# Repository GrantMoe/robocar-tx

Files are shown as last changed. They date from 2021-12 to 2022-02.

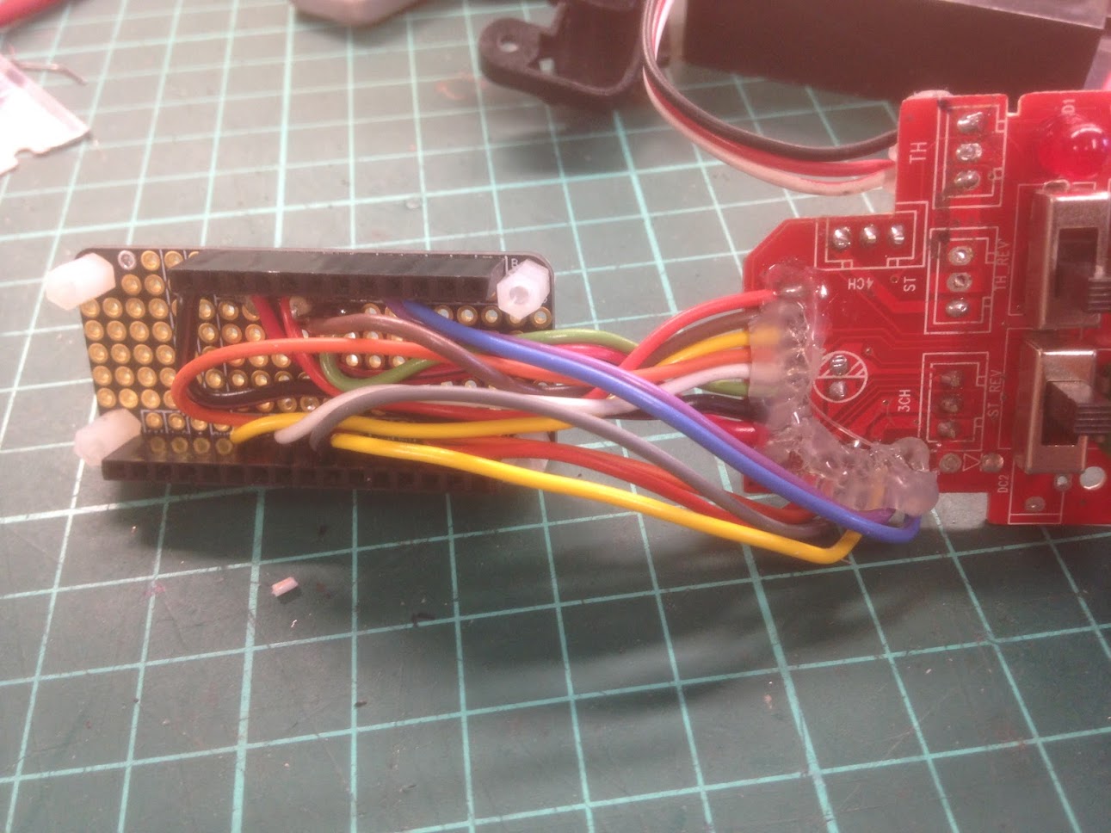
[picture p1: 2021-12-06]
mess_of_wires.JPG

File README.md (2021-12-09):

# BLE Robocar Controller

I'm building an autonomous RC car to participate in diy [DIYRobocar](https://diyrobocars.com/) events.

My 2-channel RC radio wasn't cutting it, so I decided to make my own BLE controller.

### Components

* [Adafruit Feather nRF52 Bluefruit LE - nRF52832](https://www.adafruit.com/product/3406)
* [Adafruit Mini Color TFT with Joystick FeatherWing](https://www.adafruit.com/product/3321)

### Todo
- [x] analog input for steering, throttle, trim pots, switches, etc
- [x] TFT/seesaw joystick and button input 
- [x] approximate Arduino's Serial dislpay via TFT screen
- [x] transmit control inputs to car
- [x] implement other car parameters (end stops, center point, max throttle, etc.) in software
- [ ] TFT menu to manipulate the above parameters
- [ ] send paramater changes to the car
- [ ] get state from car 

### tbd
* proper refresh rate

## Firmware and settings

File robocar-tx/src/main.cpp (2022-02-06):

#include <Arduino.h>
#include <Adafruit_GFX.h>
#include <Adafruit_ST7735.h>
#include <bluefruit.h>

#include "Adafruit_miniTFTWing.h"
#include "Axis.h"
#include "tx.h"

BLEDis  bledis;
BLEHidGamepad blegamepad;

// defined in hid.h from Adafruit_TinyUSB_Arduino
hid_gamepad_report_t gp;

Adafruit_miniTFTWing ss;
Adafruit_ST7735 tft = Adafruit_ST7735(TFT_CS_PIN, TFT_DC_PIN, TFT_RST_PIN);
// GFXcanvas1 canvas(tft.width(), tft.height());
// Tx_tft tx_display(tft, canvas);

// in, trim, exp, rev
Axis steering(ST_PIN, ST_TRM_PIN, ST_EXP_PIN, ST_REV_PIN);
Axis throttle(TH_PIN, TH_TRM_PIN, TH_EXP_PIN, TH_REV_PIN);

String id_str = "EF:EB:FD:C7:F8:DA";
int current_mode;
int previous_mode;
bool reversed = true;

// TODO: callbacks can be useful for hand unit display, actually.
void connect_callback(uint16_t);
void disconnect_callback(uint16_t, uint8_t);
void startAdv(void);
int read_slider(int);
void show_menu(int);
void print_scroll(String);
int miniTFTWing_gamepad_buttons(int, bool);
int miniTFTWing_gamepad_hat(int, bool);


const unsigned long tft_buttons[] = {
  TFTWING_BUTTON_DOWN,
  TFTWING_BUTTON_UP,
  TFTWING_BUTTON_RIGHT,
  TFTWING_BUTTON_LEFT,
  TFTWING_BUTTON_SELECT,
  TFTWING_BUTTON_A,
  TFTWING_BUTTON_B
};

const String menu_strings_[3][3] = {
  {"", "", "Drive"},
  {"confirm", "cancel", "Cal."},
  {"center", "calibrate", "Pause"}
};

bool pressed[NUM_BUTTONS];
unsigned long last_pressed[NUM_BUTTONS];


void setup() {

  for (int i =0; i < NUM_BUTTONS; i++) {
    pressed[i] = false;
    last_pressed[i] = millis();
  }
  // set reverse switch pullups
  // do in axis instead?
  pinMode(ST_REV_PIN, INPUT_PULLUP);
  pinMode(TH_REV_PIN, INPUT_PULLUP);
  pinMode(CH_4_PIN, INPUT);

  Serial.begin(9600);

  //---------
  // TFT Wing
  //---------
  if(!ss.begin()) {
    Serial.println("seesaw couldn't be found!");
    while(1);
  }
  Serial.println("seesaw started");
  ss.tftReset();
  ss.setBacklight(TFTWING_BACKLIGHT_ON);

  tft.initR(INITR_MINI160x80);
  tft.cp437(true);
  if (reversed) {
    tft.setRotation(1); // reverse for controller config
  }
    tft.fillScreen(ST77XX_BLACK);
  // delay(200);
  Serial.println("TFT initialized");
  

  // ---------
  // BlueFruit
  // ---------
  // Config the peripheral connection with maximum bandwidth 
  // more SRAM required by SoftDevice
  // Note: All config***() function must be called before begin()
  // Bluefruit.configPrphBandwidth(BANDWIDTH_MAX);
  Bluefruit.begin();
  Bluefruit.setTxPower(4);    // Check bluefruit.h for supported values

  // Bluefruit.setName(getMcuUniqueID()); // useful testing with multiple central connections
  Bluefruit.Periph.setConnectCallback(connect_callback);
  Bluefruit.Periph.setDisconnectCallback(disconnect_callback);

  // Configure and Start Device Information Service
  bledis.setManufacturer("Adafruit Industries");
  bledis.setModel("Bluefruit Feather52");
  bledis.begin();

  // Configure BLE HID
  blegamepad.begin();

  /* Set connection interval (min, max) to your perferred value.
   * Note: It is already set by BLEHidAdafruit::begin() to 11.25ms - 15ms
   * min = 9*1.25=11.25 ms, max = 12*1.25= 15 ms
   */
  /* Bluefruit.Periph.setConnInterval(9, 12); */

  // Set up and start advertising
  startAdv();
  Serial.println("started advertising");
  print_scroll("Dev ID : " + id_str);

  previous_mode = PAUSE_MODE;
  current_mode = PAUSE_MODE;
  show_menu(current_mode);
}

void startAdv(void)
{
  // Advertising packet
  Bluefruit.Advertising.addFlags(BLE_GAP_ADV_FLAGS_LE_ONLY_GENERAL_DISC_MODE);
  Bluefruit.Advertising.addTxPower();
  Bluefruit.Advertising.addAppearance(BLE_APPEARANCE_HID_GAMEPAD);
  Bluefruit.Advertising.addService(blegamepad);
  Bluefruit.ScanResponse.addName();
  
  /* Start Advertising
   * - Enable auto advertising if disconnected
   * - Interval:  fast mode = 20 ms, slow mode = 152.5 ms
   * - Timeout for fast mode is 30 seconds
   * - Start(timeout) with timeout = 0 will advertise forever (until connected)
   * 
   * For recommended advertising interval
   * https://developer.apple.com/library/content/qa/qa1931/_index.html   
   */
  Bluefruit.Advertising.restartOnDisconnect(true);
  Bluefruit.Advertising.setInterval(32, 244);    // in unit of 0.625 ms
  Bluefruit.Advertising.setFastTimeout(30);      // number of seconds in fast mode
  Bluefruit.Advertising.start(0);                // 0 = Don't stop advertising after n seconds  
}

void loop() {
  // Serial.println("loop!");
  // display menu

    // handle sliders
  int steering_out = steering.getOuput();
  // int throttle_out = throttle.getOuput();
  int throttle_out = analogRead(TH_PIN);
  int ch3_in = analogRead(CH_3_PIN);
  int ch3_out = read_slider(ch3_in);
  int ch4_in = digitalRead(CH_4_PIN);
  int ch4_out = 0;

  // pretend it's an axis for right now
  if (ch4_in == HIGH) {
    ch4_out = MAX_OUT;
  } else {
    ch4_out = MIN_OUT;
  }

  unsigned long time_ms = millis();
  
  int ss_btns = ss.readButtons();

  // handle for the sake of tx menu debounce
  for (int i = 0; i < NUM_BUTTONS; i++) {
    pressed[i] = false;
    if (! (ss_btns & tft_buttons[i])) {
      if (time_ms - last_pressed[i] > COOLDOWN) {
        pressed[i] = true;
        last_pressed[i] = time_ms;
      }
    }
  }

  switch(current_mode) {
  case DRIVE_MODE:
      // check if pausing 
    if (ch4_in == HIGH) {
      current_mode = PAUSE_MODE;
    }
    // anything else to do here?
    break;
  case CALIBRATE_MODE:
    if (pressed[button::tft_b] == true) {
      // confirm calibration, apply new values
      steering.applyCalibration();
      throttle.applyCalibration();
      current_mode = PAUSE_MODE;
    } else if (pressed[button::tft_a] == true) {
      // end calibrate mode without apply calibration
      current_mode = PAUSE_MODE;
    } else {
      // continue calibrating
      steering.calibrate();
      throttle.calibrate();
    }
    break;
  default: // pause mode
    if (pressed[button::tft_a]){
      // start calibration as ordered
      current_mode = CALIBRATE_MODE;
      steering.startCalibration();
      throttle.startCalibration();
    } else if (pressed[button::tft_b]) {
      // center axes
      steering.center();
      throttle.center();
      } else {
    // don't start drive and calibration at the same time
      if (ch4_in == LOW) {
        current_mode = DRIVE_MODE;
      }
    }
  } 


  // ble gamepad : hid axis (jstest-gtk)
  // x   : 0 (circle 1 horz)
  // y   : 1 (circle 1 vert)
  // z   : 2 (circle 2 horz)
  // rz  : 5 (bar 2)
  // rx  : 3 (circle 2 vert)
  // ry  : 4 (bar 1)
  // hat : NONE
  // gp.buttons
  // ??  : 6
  // ??  : 7

  // hid : ble : jstest-gtk
  // 0 : x  : circle 1 horz
  // 1 : y  : circle 1 vert
  // 2 : z  : circle 2 horz
  // 3 : rx : circle 2 vert
  // 4 : ry : bar 1
  // 5 : rz : bar 2
  // 6 : ??
  // 7 : ??
  Serial.print("steering out: ");
  Serial.println(steering_out);
  Serial.print("throttle out: ");
  Serial.println(throttle_out);
  Serial.println("=======");

  // transmit report
  gp.x = steering_out;
  gp.y = throttle_out;
  gp.ry = ch3_out;
  gp.rz = ch4_out;
  gp.hat = miniTFTWing_gamepad_hat(ss_btns, reversed);
  gp.buttons = miniTFTWing_gamepad_buttons(ss_btns, reversed);

  blegamepad.report(&gp);

  if (current_mode != previous_mode) {
    show_menu(current_mode);
  }
  previous_mode = current_mode;
}

int miniTFTWing_gamepad_buttons(int raw_buttons, bool reversed) {
  // there are only really three buttons currently.
  // Adafruit_TinyUSB_Arduino/src/class/hid/hid.h
  // adafruit : linux
  // GAMEPAD_BUTTON_SOUTH : GAMEPAD_BUTTON_0
  // GAMEPAD_BUTTON_EAST : GAMEAPAD_BUTTON_1
  // GAMEPAD_BUTTON_NORTH : GAMEPAD_BUTTON_3
  // GAMEPAD_BUTTON_WEST : GAMEPAD_BUTTON_4
  // GAMEPAD_BUTTON_SELECT : GAMEPAD_BUTTON_10
  // note: https://www.kernel.org/doc/html/latest/input/gamepad.html
  uint32_t gamepad_buttons = 0;
  if (! (raw_buttons & TFTWING_BUTTON_A)) {
    gamepad_buttons |= reversed ? GAMEPAD_BUTTON_SOUTH : GAMEPAD_BUTTON_EAST;
  }
  if (! (raw_buttons & TFTWING_BUTTON_B)) {
    gamepad_buttons |= reversed ? GAMEPAD_BUTTON_EAST : GAMEPAD_BUTTON_SOUTH;
  }
  // // joystick switches
  // if (! (raw_buttons & TFTWING_BUTTON_RIGHT))

  if (! (raw_buttons & TFTWING_BUTTON_SELECT)) {
    gamepad_buttons |= GAMEPAD_BUTTON_SELECT;
  }
  return gamepad_buttons;
}

int miniTFTWing_gamepad_hat(int raw_buttons, bool reversed) {
  int hat = 0;
  if (! (raw_buttons & TFTWING_BUTTON_LEFT)) {
    if (! (raw_buttons & TFTWING_BUTTON_DOWN)) {
      hat = reversed ? GAMEPAD_HAT_UP_RIGHT : GAMEPAD_HAT_DOWN_LEFT;
    } else if (! (raw_buttons & TFTWING_BUTTON_UP)) {
      hat = reversed ? GAMEPAD_HAT_DOWN_RIGHT : GAMEPAD_HAT_UP_LEFT;
    } else {
      hat = reversed ? GAMEPAD_HAT_RIGHT : GAMEPAD_HAT_LEFT;
    }
  } else if (! (raw_buttons & TFTWING_BUTTON_RIGHT)) {
    if (! (raw_buttons & TFTWING_BUTTON_DOWN)) {
      hat = reversed ? GAMEPAD_HAT_UP_LEFT : GAMEPAD_HAT_DOWN_RIGHT;
    } else if (! (raw_buttons & TFTWING_BUTTON_UP)) {
      hat = reversed ? GAMEPAD_HAT_DOWN_LEFT : GAMEPAD_HAT_UP_RIGHT;
    } else {
      hat = reversed ? GAMEPAD_HAT_LEFT : GAMEPAD_HAT_RIGHT;
    }
  } else if (! (raw_buttons & TFTWING_BUTTON_DOWN)) {
    hat = reversed ? GAMEPAD_HAT_UP : GAMEPAD_HAT_DOWN;
  } else if (! (raw_buttons & TFTWING_BUTTON_UP)) {
    hat = reversed ? GAMEPAD_HAT_DOWN : GAMEPAD_HAT_UP;
  } else {
    hat = GAMEPAD_HAT_CENTERED; // redundant but whatever 
  }
  return hat;
}

int read_slider(int val) {
  if (val > SLIDER_HIGH) {
    return MAX_OUT;
  } else if (val < SLIDER_LOW) {
    return MIN_OUT;
  } else {
    return NEUTRAL_OUT;
  }
}

// callback invoked when central connects
void connect_callback(uint16_t conn_handle)
{
  // Get the reference to current connection
  BLEConnection* connection = Bluefruit.Connection(conn_handle);

  char central_name[32] = { 0 };
  connection->getPeerName(central_name, sizeof(central_name));

  Serial.print("Connected to ");
  Serial.println(central_name);
  print_scroll("Connected: ");
  print_scroll("  " + String(central_name));
}

/**
 * Callback invoked when a connection is dropped
 * @param conn_handle connection where this event happens
 * @param reason is a BLE_HCI_STATUS_CODE which can be found in ble_hci.h
 */
void disconnect_callback(uint16_t conn_handle, uint8_t reason)
{
  (void) conn_handle;
  (void) reason;
  Serial.println();
  Serial.print("Disconnected, reason = 0x"); 
  Serial.println(reason, HEX);
  print_scroll("");
  print_scroll("Disconnected:"); 
  print_scroll(" reason = 0x" + String(reason, HEX));
  print_scroll("\n Dev ID :" + id_str); // in case you need to re-enter
}

void show_menu(int mode) {
  tft.fillScreen(ST77XX_BLACK);
  tft.setTextSize(1);
  tft.setCursor(0, 10);
  tft.print(menu_strings_[mode][0]);
  tft.setCursor(0, 60);
  tft.print(menu_strings_[mode][1]);
  tft.setCursor(20, 27);
  tft.setTextSize(3);
  tft.print(menu_strings_[mode][2]);
}

void print_scroll(String new_str) {
  static int scroll_size = 9;
  static int scroll_called;
  static String scroll_strs[] = {"", "", "", "", "", "", "", "", ""};
  tft.setTextWrap(false);
  tft.setCursor(0, 0);
  tft.setTextColor(ST7735_WHITE, ST77XX_BLACK);  // should be grey
  tft.setTextSize(1);
  if (scroll_called < scroll_size) {
    scroll_strs[scroll_called] = new_str;
    scroll_called++;
  }
  else {
    for (int i_shift = 1; i_shift < scroll_size; i_shift++) {
      scroll_strs[i_shift-1] = scroll_strs[i_shift]; 
    }
    scroll_strs[scroll_size-1] = new_str;
  }
  for (int i_print = 0; i_print < scroll_size; i_print++) {
    tft.print(scroll_strs[i_print]);
    if (tft.getCursorX() < tft.width()) {
      tft.fillRect(tft.getCursorX(), tft.getCursorY(), 
                  tft.width() - tft.getCursorX(), 16, ST77XX_BLACK);
    }
    tft.print('\n');
  }
}

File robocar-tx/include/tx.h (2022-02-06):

#ifndef TX_H
#define TX_H

#define CH_3_PIN 30
#define CH_4_PIN 11
#define ST_PIN 2
#define ST_EXP_PIN 3
#define ST_REV_PIN 16
#define ST_TRM_PIN 4
#define TH_PIN 28
#define TH_EXP_PIN 29
#define TH_REV_PIN 27
#define TH_TRM_PIN 5
#define TFT_DC_PIN 15
#define TFT_CS_PIN 7
#define TFT_RST_PIN -1

#define DRIVE_MODE 0
#define CALIBRATE_MODE 1
#define PAUSE_MODE 2

#define MIN_IN 0
#define NEUTRAL_IN 512
#define MAX_IN 1023
#define MIN_OUT -127
#define NEUTRAL_OUT 0
#define MAX_OUT 127
#define SLIDER_HIGH 682
#define SLIDER_LOW 341

#define NUM_BUTTONS 7
enum button { 
    joy_up, 
    joy_down, 
    joy_left, 
    joy_right, 
    joy_select, 
    tft_a,
    tft_b};

#define DEBOUNCE 100
#define COOLDOWN 500

#endif

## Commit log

2021-08-20 Update .gitignore
    Copy over a Platformio/Arduino/Python .gitignore from another project
2021-08-21 Create VS Code project
    Add transmitter pcb pin enums and a Adafruit TFT flash
2021-08-21 Add axes and button input processing
    - Read analog and digital pins connected to the RC
    transmitter axes and switches/buttons
    - Grab button data from TFT featherwing
    - Convert analog input (0-1023) to bytes
    - Bitwise buttons into their own byte
2021-08-23 Add basic BLE Uart test with TFT reporting
    - Copy code from the Adafruit BLEUart example
    - Replace serial print/println with TFT versions
    [main.cpp]
2021-08-23 Fix TFT scrolling print
    - Fix index error and flashing screen on redraw
    [main.cpp]
2021-08-25 Add input processing and transmission
    - Add trim and exponent functionality for steering
    and throttle input
    - Write combined inputs as bytes to BLE output buffer
2021-10-12 Add Pin/Controller Info
2021-12-09 Modify status print style
2021-12-09 Mid-change laptop switch
2021-12-10 Correct input mapping for steering/throttle input, trim
    Determined the maximum and minimum values returned by
    analogread in the current configuration and adjusted
    accordingly.
    Should now map to the full 0-255 range.
    [main.cpp]
2021-12-15 Switch to gamepad uuid (and let the kernel handle most everything)
    As it turns out, it's way easier just to call the controller a gamepad,
    per the adafruit bluefruit example.
    The return display is a nice thought but kinda extraneous at the moment.
    I'll revisit it later.
    Feeding the seesaw button int right into the gampad's button int works.
2021-12-16 Create Axis class to handle steering and throttle
    Split off the input/processing functions from main to keep things a
    bit tidier.
    Included code to recalibrate endpints due to ridiculous reading shifts
    from the hand unit.
2021-12-16 Major refactor of main
    Remove analog processing code to its own class (Axis), change how sliders
    are processed. Begin to implement different drive/calibrate menus.
    Comment out the disconnect/connect callbacks; they aren't in the Adafruit
    example, and theit absences does not seem to affect functioning in tests
    thus far.
2021-12-20 Re-integrate GUI to main loop, add switch debounce handling.
    Further refining/debugging the transmitter tft GUI.
    Last presses of buttons are now tracked; if the current press is within
    too short of an interval it is ignored. Note that the raw input is still
    being transmitted to the car; this is for the tx unit only right now.
    The separate tft class was proving to be a bit of a pain so I dropped it
    for now.
    [main.cpp, tx.h]
2021-12-22 Add axis-centering function.
    Due to the transimitter's construction, the "centered" position
    of the input potentiometers (defined either by spring tention
    for steering and throttle or arrow direction for the trim pots)
    might not correspond to the middle point between minimum and
    maximum analog readings.
    A centering option has been added to the pause menu screen, and
    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
2022-01-03 Add KICAD project
    Upload a simple starter KICAD project, currently an incomplete schematic,
    for a replacement potentiometer/buttons/power PCB.
    [tx-pcb.kicad_pcb, tx-pcb.kicad_sch]
2022-02-06 Add debugging prints, tweak input/output max/mins.
    Mostly pushing to work on my laptop.
